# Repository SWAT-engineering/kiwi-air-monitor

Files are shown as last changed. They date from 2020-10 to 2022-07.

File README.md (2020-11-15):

<p align="center">
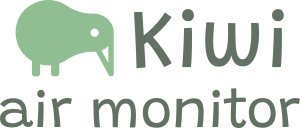
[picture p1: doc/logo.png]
Kiwi Monitor logo
    
</p>

Kiwi air monitor is an open source CO2/Humidity/Temperature sensor intended for monitoring the indoor air quality. Kiwi air monitor was initiated by [swat.engineering](https://www.swat.engineering) to support teachers and school organizations with the ventilation of the class rooms. 

## Features

- Monitor CO2, Humidity, Temperature, Atmospheric Pressure 
- Display current measurements and its trend on a small display
- Blink a warning light if certain thresholds are reached (> 800ppm CO2 for example)
- Optionally: publish sensor readings to a (self hosted) MQTT server to allow building wide monitoring
- Optionally: partial remote control via MQTT
- Optionally: Updating firmware over wifi (OTA) 
- Optionally: Docker-compose based Dashboard & MQTT server setup

<p align="center">
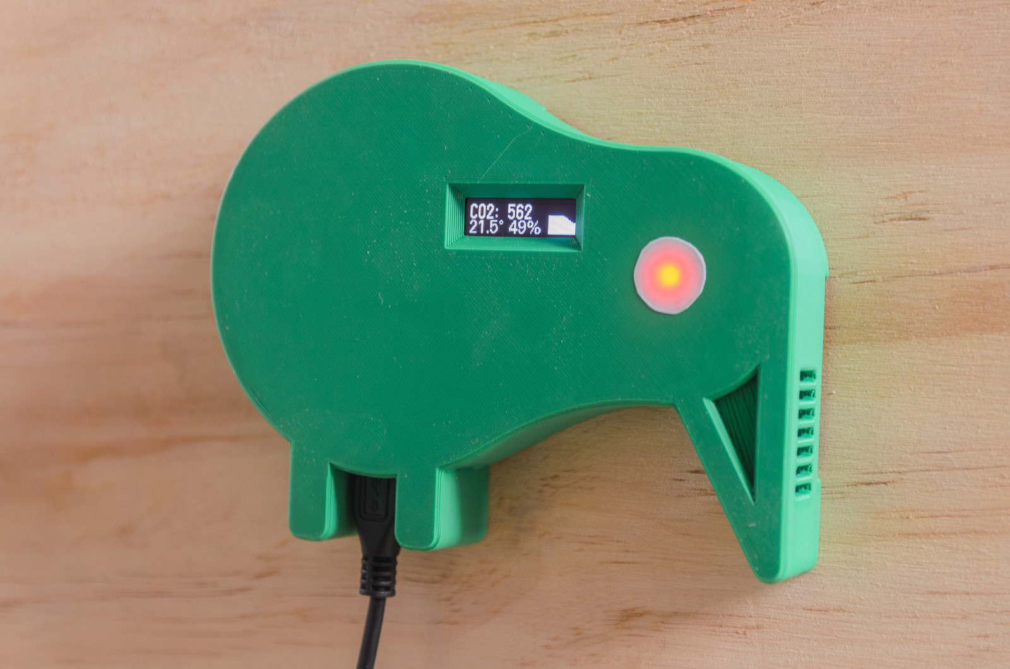
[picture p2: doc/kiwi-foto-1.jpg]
    
</p>

Due to the cost-cutting concern, we have focussed more on precision instead of accuracy. Meaning that if a value increases, it should indeed represent an increase in that property, but it is acceptable to have a bias with respect to more expensive measurements. So you might get a temperature of 20.4 degrees C even though it iss actually 20.9 degrees C but if it increases to 20.5 degrees C it indeed is now 21.0 degrees C.

## Hardware

The hardware is build around the ESP8266 platform. The costs (in the Netherlands) are roughly €45-50 per device. The list of components and schemas can be found in [doc/NL/Hardware.md](doc/NL/Hardware.md). We also provide a 3D model to print.

## Documentation
Please check out the documentation for further details and instructions about hardware and software, and user manuals:

1. [Dutch](doc/NL/)
2. [English](doc/ENG/) 

## Server

We've developed a small server setup (docker-compose based) so you can get started yourself. Checkout the [server/](server/) directory and the corresponding [documentation](docs/NL/Software.md).

## License

The software and 3D models are all [GPLv3 licensed](LICENSE). We use libraries with  compatible licenses. See [Software documentation](doc/NL/Software.md) for a list of which libraries are used.

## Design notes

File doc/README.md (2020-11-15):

This folder contains most documentation of the Kiwi Air Monitor.

The [Dutch Manual](NL/) is currently the most complete. 
Once it is finished we'll start translating it to [English](ENG/).

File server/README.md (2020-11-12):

# Server documentation & setup for Kiwi

The Kiwi Air Monitor can optionally send measurements to an MQTT server. This allows for building management and remote updates of settings & firmware.

This directory contains:

- `demo-config`: a docker-compose configuration for mqtt, influx, our own forwarder from mqtt to influx, and grafana for dashboards
- `mqtt-2-influx`: a small forwarder that takes kiwi sensor messages, optionally adds extra tags (such as building specific meta data) and inserts it into the `kiwi` database on influx
- `generator`: a small program that can fake one or more kiwi sensors. This is useful for testing and developing the server side.
- `doc`: documentation about the mqtt messages, and several setup related documentation and advice

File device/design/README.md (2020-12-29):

# The Kiwi Monitor hardware

These are the design files for the version1.0 PCB of the Kiwi Air Monitor. The project has been designed using KiCad EDA.

All components can be "plugged" into the board on the female header connectors.

See the [../../doc/](../../doc/) folder for design documentation.

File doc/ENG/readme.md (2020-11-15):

This folder will contain the english instructions. Sorry, we are currently working on the Dutch documentation, but we would love contributions for translations, but be warned, the Dutch translation is still in flux at the moment.

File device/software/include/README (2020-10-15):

Configuration file for you version of the Kiwi sensor.

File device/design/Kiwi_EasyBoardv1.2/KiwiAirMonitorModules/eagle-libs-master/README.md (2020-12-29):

Eagle Libraries
===============

Footprints of some electronic parts for Eagle v6.0 or greater:

 * **mh-z19.lbr** - [MH-Z19 NDIR CO2 sensor module](http://eleparts.co.kr/data/design/product_file/SENSOR/gas/MH-Z19_CO2%20Manual%20V2.pdf)

License Information
-------------------

This library collection is released under the [Creative Commons ShareAlike 4.0 International](https://creativecommons.org/licenses/by-sa/4.0/) license. Feel free to use these libraries for any purposes.

Improvements and fixes are welcome. Just fork repository, modify it and create pull request with changes.

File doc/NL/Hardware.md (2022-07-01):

# Hardware

Om alle componenten op een makkelijke en zekere manier met elkaar te verbinden hebben we een PCB ontworpen zoals hieronder te zien. We zijn nog bezig een manier te vinden dit PCB voor anderen beschikbaar te maken.

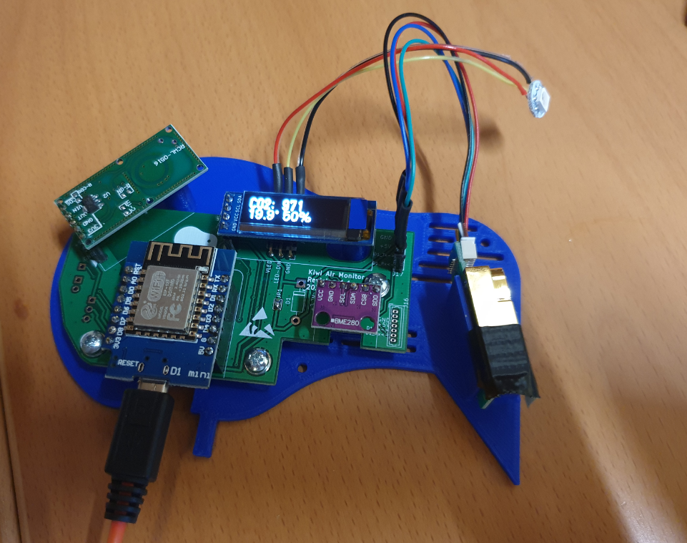
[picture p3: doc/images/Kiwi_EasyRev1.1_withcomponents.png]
KiwiEasyBoard Rev1.1


## Bestellijst 

De hardware is ontworpen rondom een ESP8266 platform. De kosten voor alle componenten zijn ongeveer 45-50 euro per apparaat. Hieronder links naar de verschillende componenten (hoeft niet perse daar gekocht te worden). 

- [Wemos D1 Mini - ESP8266-12F](https://www.tinytronics.nl/shop/en/communication/wi-fi/d1-mini-esp8266-12f-ch340) Zorg ervoor dat je de versie koopt met de "deksel" deze is FCC gekeurd en geeft minder storing op de bewegingssensor.
- [Winsen MH-Z19C CO2 Sensor](https://www.tinytronics.nl/shop/nl/sensoren/temperatuur-lucht-vochtigheid/winsen-mh-z19c-co2-sensor-met-kabel): We gebruiken nu de **versie C**. Deze is stabieler dan de versie B en volgens de specificaties ook nauwkeuriger. Deze versie word op het PCB aangesloten met het bijgeleverde kabeltje via een 7-pins PicoBlade connector. Vanwege hoge temperaturen word solderen direct op de sensor afgeraden. De MH-Z19 is een NDIR-type CO2 sensor, die na calibratie een goede sensitiviteit heeft. De nauwkeurigheid is echter niet vergelijkbaaar met een industriele sensor (4 a 5 keer zo duur). De echte CO2 waarde kan ongeveer 50 ppm hoger of lager zijn, maar de trend en de grove waardes zijn voor dit doeleinde meer dan genoeg.
- [BME280 I2C Temperature/Humidity Sensor](https://www.tinytronics.nl/shop/nl/sensoren/temperatuur-lucht-vochtigheid/bme280-digitale-barometer-druk-en-vochtigheid-sensor-module): zorg ervoor dat je een versie aanschaft die geconfigureerd is voor I2C, of zorg ervoor dat je het om kunt zetten van SPI naar I2C. BMP280 is ook prima. [Tests](http://www.kandrsmith.org/RJS/Misc/Hygrometers/calib_many.html) hebben laten zien dat de metingen accuraat en stabiel zijn. Afhankelijk hoe de sensor geconfigureerd wordt, zal de temperatuur een beetje onder of boven de echte waar zijn. Soldeer de header connector zo, dat de sensor aan de onderkant zit.
- [RCWL-0516 movement sensor](https://www.tinytronics.nl/shop/en/communication/rf/microwave-movement-sensor-rcwl-0516) een kleine sensor die beweging tot 7 m kan detecteren. In dit project wordt deze vooral gebruikt om te detecteren of er mensen aanwezig zijn en of het dus nodig is om iets op het display van de kiwi air monitor te laten zien (of dat het scherm uit kan). Soldeer de header connector zo, dat de componenten aan de onderkant zitten en de labels aan de bovenkant. 
- [SSD1306 128x32 OLED screen I2C](https://www.tinytronics.nl/shop/nl/display/oled/0.91-inch-oled-display-128*32-pixels-wit-i2c): zorg ervoor dat het een I2C versie is en een SSD1306 chipset heeft. Merk maakt niet veel uit. 
- [WS2812B RGB Led](https://www.tinytronics.nl/shop/nl/verlichting/led-digitaal/ws2812b-digitale-5050-rgb-led-printplaat-los-wit): Per apparaat is maar een ledje nodig, maar je kunt ook een hele strip kopen en er andere leuke dingen mee doen. De LED gestuurd word vanuit de D1Mini met spanning tussen 0V-3.3V. Volgens de WS2812B specificatie ligt het logisch '1' schakelniveau van deze chip op 0.7*VDD. Bij een Voedingsspanning van 5.0V zou de chip dus 3.5V op zijn data-in moeten hebben. Om dit probleem te omzeilen hebben we een diode in het voedingspad naar de LED gezet zodat we een spanning krijgen van 5.0V-0.7V=4.3V. Het logisch '1' schakel niveau komt hierdoor te liggen op 0.7 * 4.3 = 3.01V. Parallel aan de diode zit een soldeer brug.
- [7 pins Molex PicoBlade connector](https://sinuss.nl/zoeken?keyword=53047-0710): Connector om de MH-Z19C met het PCB te verbinden
- Kiwi Easyboard PCB: We hebben een PCB ontworpen waardoor de componenten makkelijk met elkaar verbonden kunnen worden.  De design files in KiCad en de gerbers zijn [hier beschikbaar](../../device/design/). De huidige versie is v1.1

Onderdelen die ook nodig zijn, maar waarvan we aannemen dat je die al hebt:
- USB oplader (500ma zou genoeg moeten zijn) of alternatief een powerbank, per dag ongeveer 800mAh rekenen.
- Micro-USB kabel
- Kabeltjes om de LED met de PCB te verbinden
- Een stel headers: Female voor op het PCB. Male voor aan de sensorren. (Sommige sensoren worden geleverd met pin headers).
- Soldeerbout
- Voor exprimenteren: Breadboard en kabeltjes om te experimenteren
  
## Stroomverbruik

De Kiwi verbruikt per uur ongeveer 30mAh. Meeste simple USB voedingen voldoen (500mA is ruim voldoende). Daarnaast zijn we een uitbreiding aan het ontwikkelen voor powerbanks erbij op te hangen. Op een powerbank van 2500mAh kun je makkelijk 3 dagen mee draaien. En powerbanks van 6000mAh of meer kun je een week mee vooruit.

## Montage instructies

### Schema

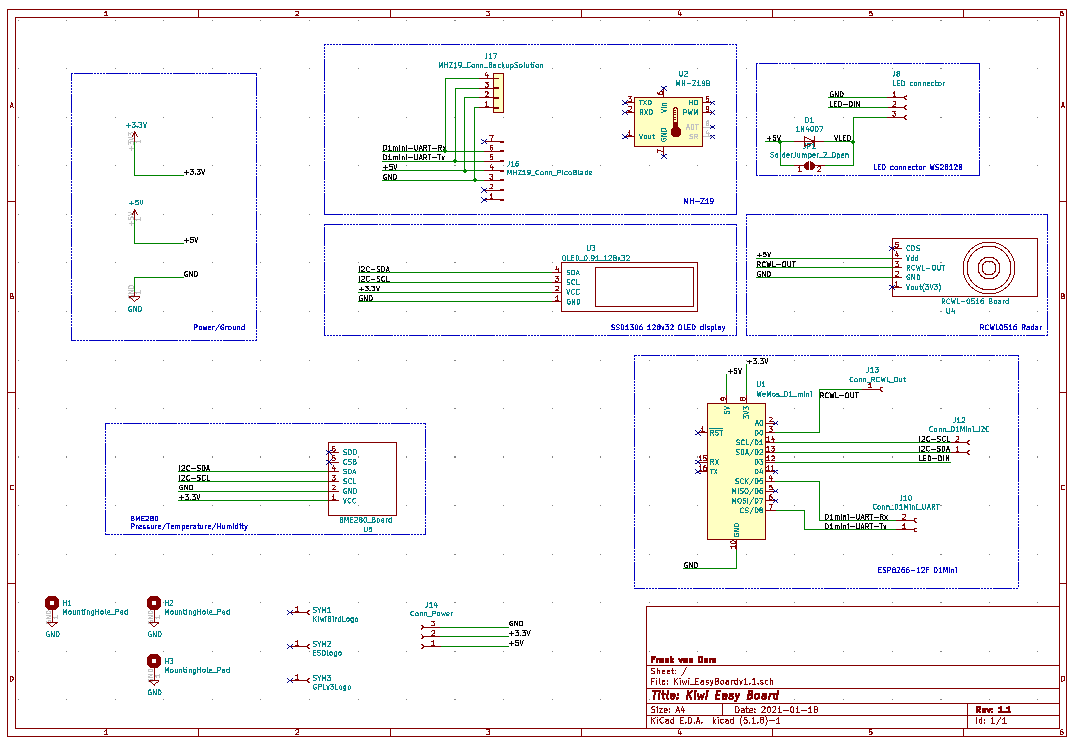
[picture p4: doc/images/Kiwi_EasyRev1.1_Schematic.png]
Wire schema
 

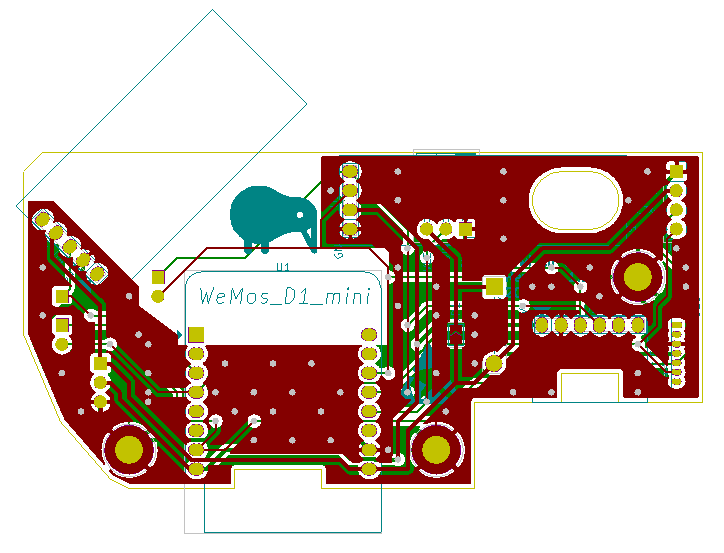
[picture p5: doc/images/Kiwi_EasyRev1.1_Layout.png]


Hieronder een samenvatting van de verbindingen:

| Component | Component side | Wemos D1 Mini |
| --- | --- | --- |
| MH-Z19C | VCC | 5V |
| | GND | G (GND) |
| | TX (Groene ader) | UART-Rx (D5) |
| | RX (Blauw ader) | UART-Tx (D8) |
| BME280 & SSD1306 | VCC | 3.3V |
| | GND | G |
| | SCL/SCK | D1 |
| | SDA | D2 |
|WS2812B | VDD | 5V |
| | VSS | G |
| | DIN | D3 |
| RCWL-0516 | VCC/VIN | 5V |
| | VOUT | D0 |
| | GND | G |

Hieronder ook het schema voor experimenten met breadboard view.

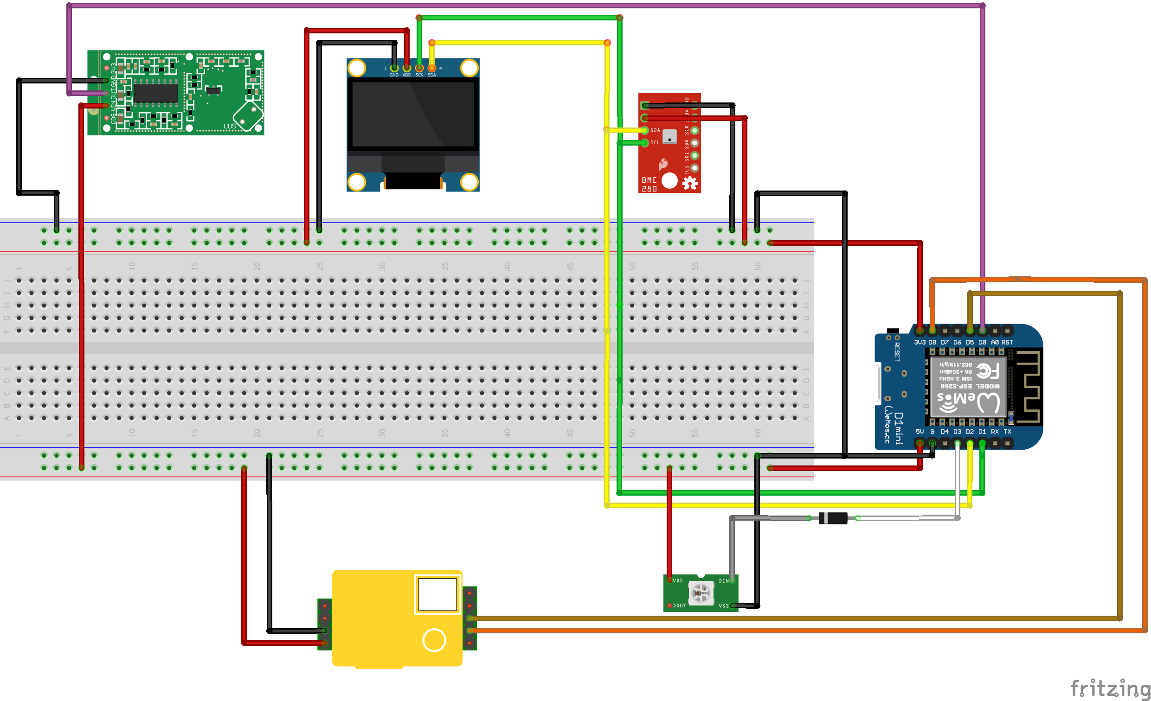
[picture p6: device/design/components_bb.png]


## Soldeer instructies

het is belangrijk de header connectors loodrecht op de PCB te solderen. Indien dit niet goed gebeurd zullen de componenten scheef komen te zitten en past het geheel misschien niet in de behuizing. Om het solderen makkelijker te maken hebben we een mal ontworpen die eenvoudig op een 3D printer is te maken.  De 3D printfile is [hier te <a href="../../device/design/Kiwi_EasyBoardv1.1/Kiwi1.1.SolderHelper.stl"> hier te vinden</a> (right-click to download)

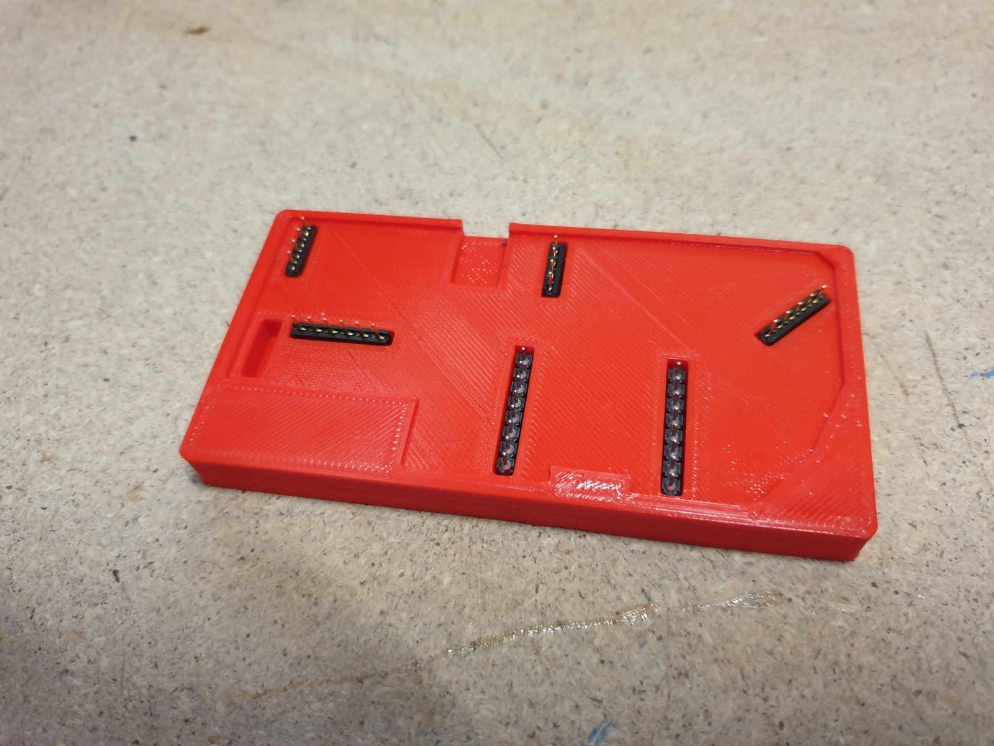
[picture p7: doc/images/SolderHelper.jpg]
Kiwi Solderhelper with PCB


Knip de header connectors eerst precies op maat en leg ze daarna in de soldeermal. Leg het PCB erboven op.

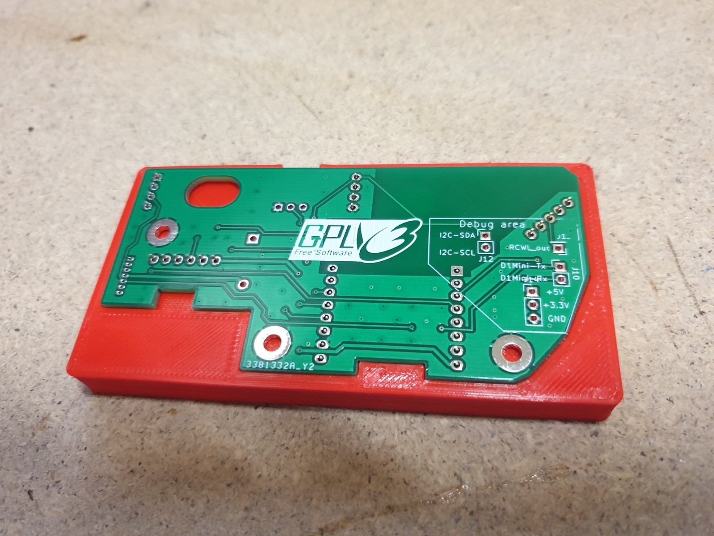
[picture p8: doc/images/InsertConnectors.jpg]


Soldeer alle pinnen netjes en check of het tin goed gevloeid heeft

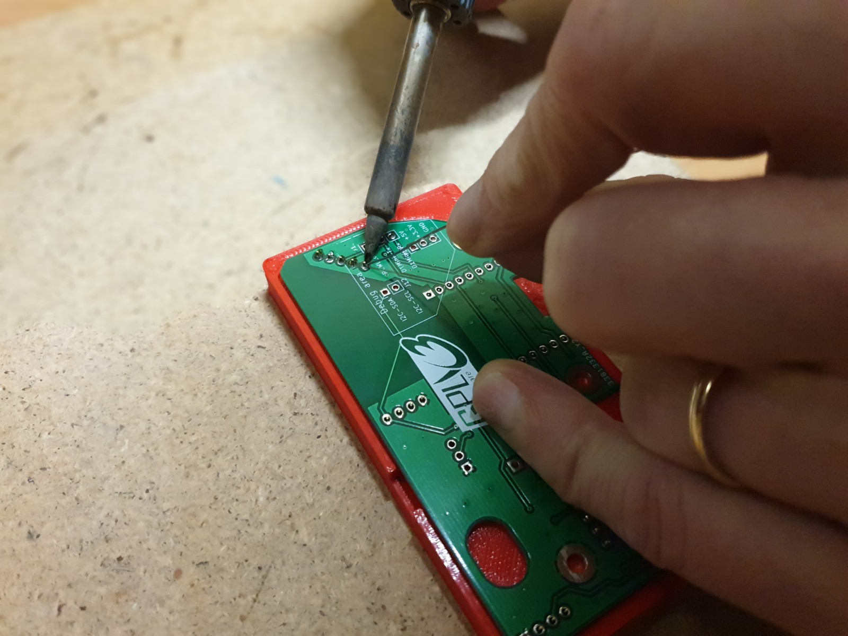
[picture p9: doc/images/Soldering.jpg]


Je PCB is nu klaar en je kunt de componenten er nu voorzichtig in drukken

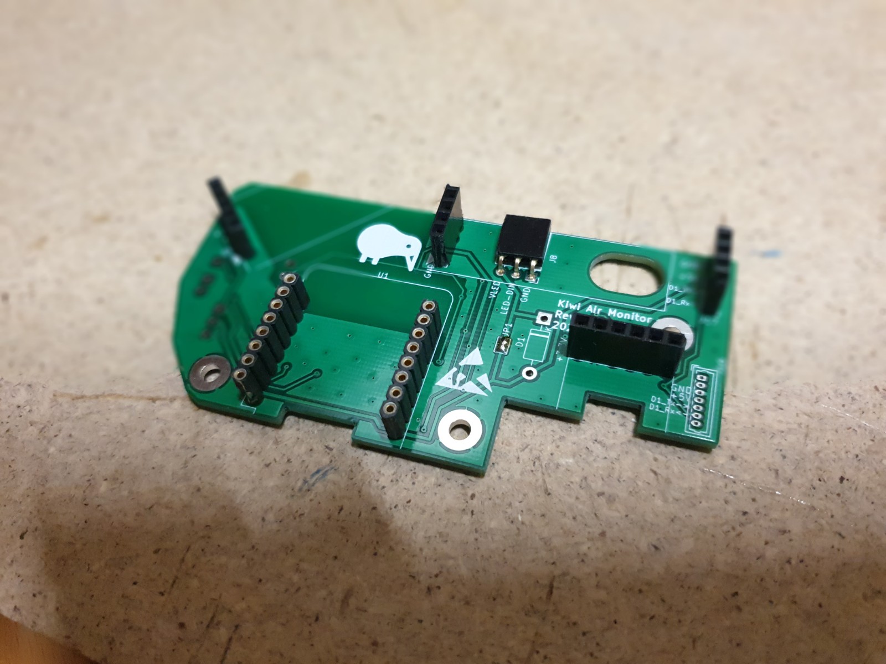
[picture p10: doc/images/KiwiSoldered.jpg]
Kiwi Solderhelper with PCB


**MH-Z19C kabel**: Op de KiwiEasyBoard 1.1 zitten 2 opties om de MH-Z19 CO2 sensor te verbinden. Het makkelijkste is het om de sensor via de meegeleverde kabel aan de 7-pins PicoBlade connector te verbinden. Indien je deze connector niet kunt verkrijgen kun je een kabel maken zoals op onderstaande foto. Op de PCB zit naast de PicoBlade ook een 4 pins header connector.

knip de connector die bij de CO2 sensor zit af aan één kant. Knip de bruine, witte en gele aders weg. Er blijven 4 over: zwart, rood, blauw, en groen. Verbind deze 4 kabels in dezelfde volgorde aan 4 pinheaders.

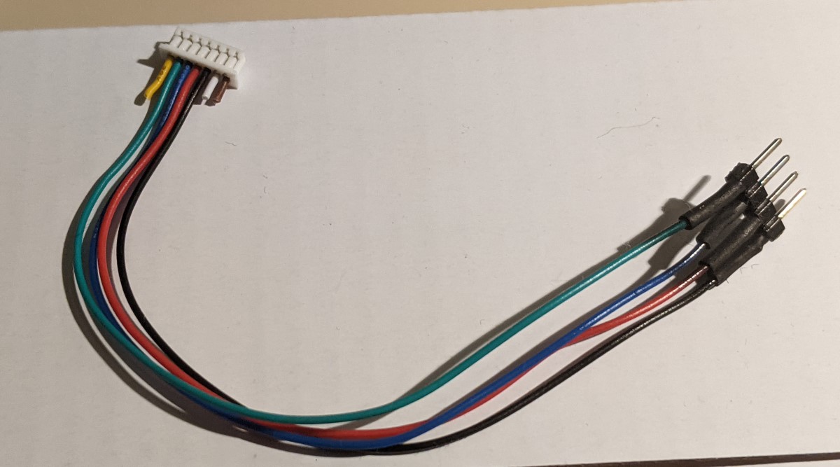
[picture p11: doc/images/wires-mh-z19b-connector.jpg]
MH-Z19B connector


## Behuizing

Om de elektronica te beschermen en netjes weg te werken, is het goed om er een behuizing om heen te maken. Er is een ontwerp gemaakt in de vorm van een kiwi vogel dat met een 3D-printer afgedrukt kan worden. In dit model passen precies alle componenten die hierboven beschreven zijn. Als je geen 3D printer tot je beschikking hebt of liever zelf iets anders maakt. Zie hieronder dan ook een aantal tips waar je aan moet denken bij het ontwerp.

### 3D-printen van behuizing

TODO: link naar 3D model + extra uitleg? eventueel een foto?

### Adviezen voor eigen ontwerp

- Zorg ervoor dat componenenten niet te dicht bij elkaar zitten
- De CO2 sensor wil graag frisse lucht, hoe er rekening mee dat er genoeg frisse lucht langs kan stromen. Zowel voor afkoeling als voor accurate meting.
- Temperatuur en lucht vochtigheids sensor willen ook frisse lucht, en hebben de voorkeur om niet te warm te worden van componenten om hen heen.
- de bewegings sensor kan storing krijgen van de ESP8266 chip, dus probeer ze niet te dicht bij elkaar te zetten.
- de bewegings sensor werkt door plastic heen, maar wil wel in 1 cm rond het object liever geen metaal. (dus ook draadjes liever niet teveel)

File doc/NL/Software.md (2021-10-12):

# Sensor software
De software voor de Kiwi air monitor is ontwikkeld voor dit project en maakt gebruik van de volgende frameworks en libraries:

- [ESP8266 Arduino Core](https://github.com/esp8266/Arduino) 
- [olikraus' U8g2](https://github.com/olikraus/U8g2)
- [Adafruit MQTT](https://github.com/adafruit/Adafruit_MQTT_Library)
- [Adafruit BME280](https://github.com/adafruit/Adafruit_BME280_Library)
- [Adafruit NeoPixel](https://github.com/adafruit/Adafruit_NeoPixel)
- [Arduino Timer](https://github.com/contrem/arduino-timer)
- [WifWafs MH-Z19](https://github.com/WifWaf/MH-Z19)

## Configuratie instructies

Het project wordt gecompileerd met [Platform IO](https://platformio.org/). 

In de bestandsmap device\software\include staat het bestand user-config-template.h, in dit bestand kan persoonlijke informatie worden aangepast.
Dit betreft informatie zoals wifi en MQTT credentials. is hier geen noodzaak voor dan hoeft het bestand niet aangepast te worden.

Na het aanpassen van het bestand dient deze opgeslagen te worden als user-config.h, belangrijk is dat het nieuw opgeslagen bestand in de bestandsmap staat als de template.
TODO: beschrijf hier de configuratie instructies

## Uploaden van firmware
De ESP8266 kan geprogrameerd worden dmv de USB aansluiting en als WiFi & MQTT geconfigureerd zijn, kan erna ook online updates uitgevoerd worden (OTA). 

### Eerste keer uploaden

Na het compileren en configureren van de Kiwi software, moet de USB kabel aan de computer worden aangesloten, en de firmware ge-upload worden.

TODO: script schrijven die dit makkelijk maakt

### Updates uitvoeren via wifi (OTA)
Als de firmware eenmaal op het apparaat staat, kunnen updates gedaan worden via wifi. 

Hiervoor moeten de volgende zaken geconfigureerd worden:

- MQTT & WIFI setup voor de Kiwi
- Signing key for the updates geconfigureeerd voor de Kiwi
- Http server waar de firmware op zal bevinden

TODO: script voor compilate & signing schrijven

## Monitoring dashboard (optioneel)
Het is mogelijk om de metingen door te sturen naar een monitoring dashboard (grafana & influxdb).
Dit biedt het de mogelijkheid om tijdstrends van de gemeten waardes per ruimte in kaart te brengen.
Hieronder volgen instructies hoe je zo'n dashboard aan kunt maken en inrichten. 
De code voor een voorbeeld-dashboard is beschikbaar in de [server directory](../../server/) van deze github repository.

### Architectuur
De verbinding met de Kiwi loopt via MQTT, dit berichten protocol ontkoppeld de Kiwi van iedereen die er interesse in heeft.
Daarnaast kan er ook gecommuniceerd worden richting de Kiwi's via MQTT.
Hierdoor wordt het mogelijk om van een afstand updates te installeren of settings aan te passen.

Een simpele forwarder stuurd MQTT berichten door naar een influx database. Deze forwarder kan ook extra annotaties aan metingen hangen, zoals de naam van een klaslokaal of een gebouw code.
Vervolgens kun je zelf een dashboard maken met [granfana](https://grafana.com/). Een initiële configuratie wordt al geboden in onze voorbeeld server setup.

In [server/mqtt.md](../../server/mqtt.md) staat beschreven welke berichten er gepubliceerd worden op de MQTT server en welke gestuurd kunnen worden richting de Kiwi.

### Voorbeeld server installatie

Als voorbeeld setup hebben wij een kleine server installatie klaargezet. Middels docker-compose kan deze op elke Linux, Windows, of OSX omgeving gedraaid worden. Het moet zelfs mogelijk zijn om een recente raspberry-pi 4 als server te gebruiken hiervoor.

De server directory bevat:
- `demo-config`: een docker configuratie voor mqtt, influx, een forwarder van mqtt naar influx, en grafana voor het visualiseren van het dashboard. 
- `mqtt-2-influx`: een forwarder die de metingen van de Kiwi air monitor (eventueel met extra tags) doorstuurt naar de `kiwi` database voor influx.
- `generator`: een klein programmaatje dat een kiwi sensor simuleert. Dit is nuttig voor het ontwikkelen en testen van de server kant.
- `doc`: een paar extra details over de mqtt berichten die niet passen in deze meer high-level handleiding.

De configuratie van de mqtt-2-influx forwarder wordt uitgelegd in de handleiding in die directory.

## Wil je bijdragen aan software ontwikkelingen?
Heb je ideeën om de software uit te breiden of aan te passen? Bijdrages zijn welkom, neem even contact met ons op van te voren om af te stemmen.

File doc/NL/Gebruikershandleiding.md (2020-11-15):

# Gebruikershandleiding

TODO: deze handleiding invullen en uitbreiden

## Wat betekenen de getallen die op de display te zien zijn?

## Kleur van het ledje

## Hoe moet ik de resultaten interpreteren?

## Wat moet ik doen als de CO2 grenswaarde wordt overschreden?

## Wat kan ik leren van de gegevens op het dashboard?

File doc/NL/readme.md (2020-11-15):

De Kiwi air monitor is een open source project waarin een sensor ontwikkeld is om de lucht kwaliteit te meten in een ruimte aan de hand van de CO2, luchtvohtigheid en temperatuur. Dit project is opgestart door [swat.engineering](https://www.swat.engineering) om docenten en schoolorganisaties te helpen bij het ventileren van de klaslokalen.

In deze folder is alle Nederlandstalige documentatie te vinden rondom het monteren en configureren van de Kiwi air monitor. 

In '[Hardware](Hardware.md)' vind je een beschrijving van de benodigde componenten, instructies voor montage en instructies met betrekking tot de behuizing.

In '[Software](Software.md)' vind je instructies rondom de software: configuratie settings, uploaden van de firmware en het monitor dashboard (optioneel)

In '[In gebruik nemen](In%20gebruik%20nemen.md)' vind je meer informatie over de stappen die genomen moeten worden nadat de hardware gemonteerd is en de software erop is gezet: calibratie van de CO2 sensor, tips voor het ophangen van de Kiwi air monitor en instructies voor het uitvoeren van software updates.

De '[Gebruikershandleiding](Gebruikershandleiding.md)' geeft nuttige tips en informatie voor de eindgebruiker van de Kiwi air monitor. 

Het document '[Educatief](Educatief.md]' is gereserveerd voor educatieve ontwikkelingen. Lijkt het je leuk om dit project om te zetten naar een lespakket voor de laatste klassen van de basisschool of voor lessen op de middelbare school, laat het ons weten en zoek contact op! 

Mochten er vragen zijn, open een [github issue](https://github.com/SWAT-engineering/kiwi-air-monitor/issues) of neem contact op met [davy.landman@swat.engineering](mailto:davy.landman@swat.engineering).

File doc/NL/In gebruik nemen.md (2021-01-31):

# In gebruik nemen

Als je de hardware en software geinstalleerd en geconfigureerd hebt, komt de volgende stap: het klaar maken voor gebruik. In dit document staat uitgelegd waar je rekening mee moet houden bij het ophangen van de kiwi en hoe je software updates kunt uitvoeren. De handleiding voor de eindgebruikers is in een appart document te vinden.

## Ophangen
Bij het ophangen van de sensor moet een geschikte plek gezocht worden in de ruimte. Houd hierbij rekening met het volgende:

TODO: lijstje met criteria voor het ophangen van de kiwi

## Onderhoud (updates)

- Updates voor de software kunnen automatisch lopen, mits dit is geconfigureerd via wifi & mqtt.
- Het ontwerp van de Kiwi is modulair, als een component beschadigd raakt, kan het makkelijk vervangen worden mits er van onze voorgestelde kabel boom gebruik is gemaakt.

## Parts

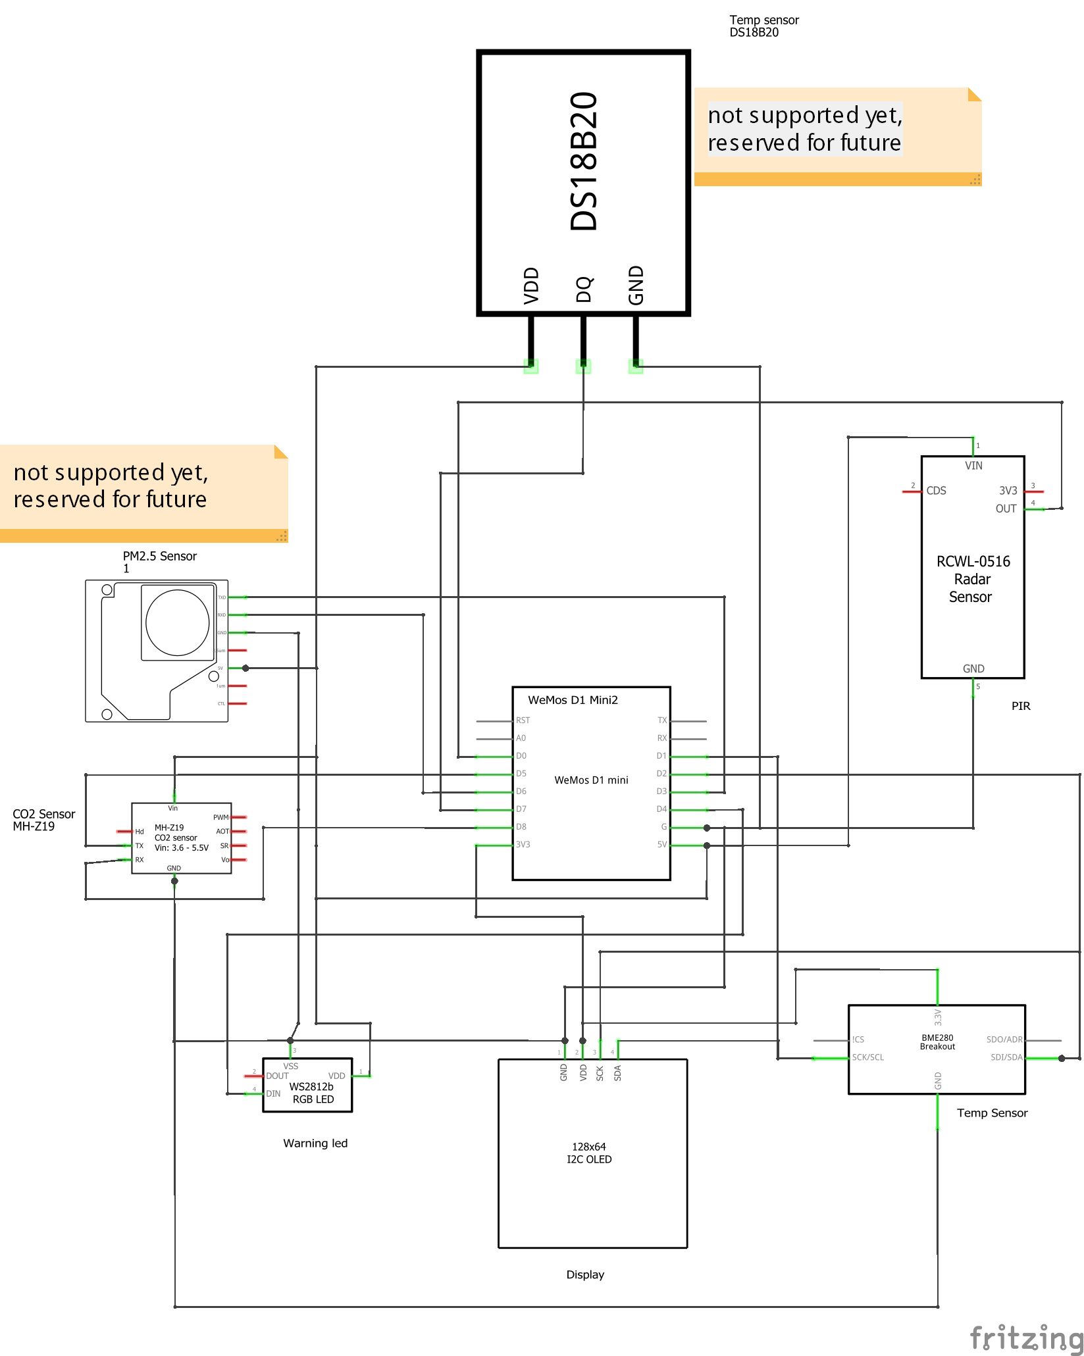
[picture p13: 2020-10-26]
device/design/components_schem.png

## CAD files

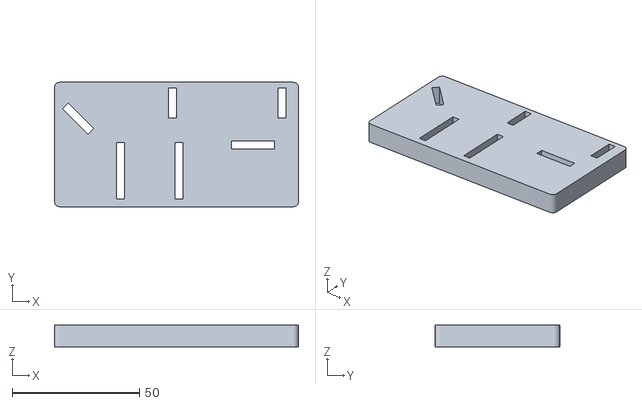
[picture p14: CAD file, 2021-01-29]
device/design/Kiwi_EasyBoardv1.1/Kiwi1.1.SolderHelper.stl
96.0 x 49.0 x 8.50

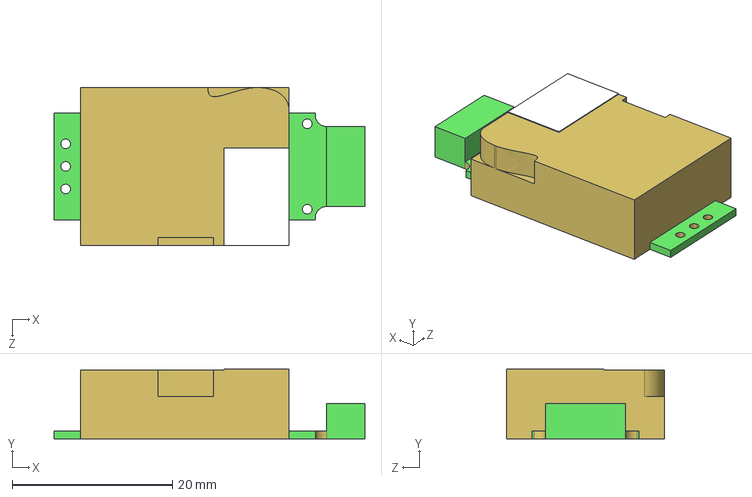
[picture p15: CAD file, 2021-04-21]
device/design/Kiwi_EasyBoardv1.2/KiwiAirMonitorModules/STEPfiles/MH-Z19C (CO2).STEP
38.8 x 8.70 x 19.7 mm

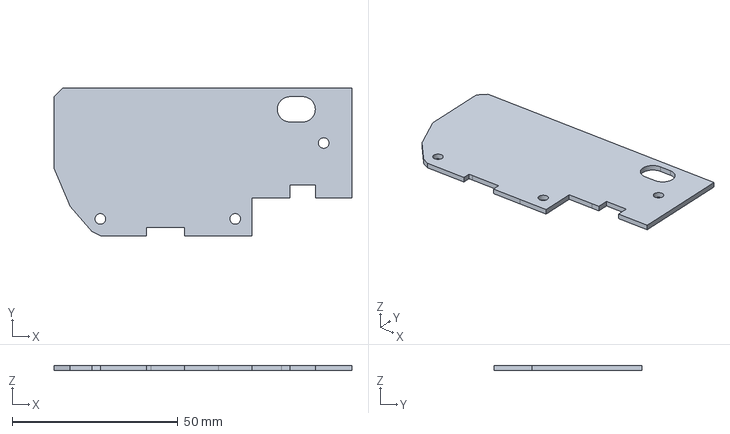
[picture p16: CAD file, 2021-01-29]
device/design/Kiwi_EasyBoardv1.1/Kiwi_EasyBoardv1.1.NoComponents.step
89.8 x 44.5 x 1.60 mm

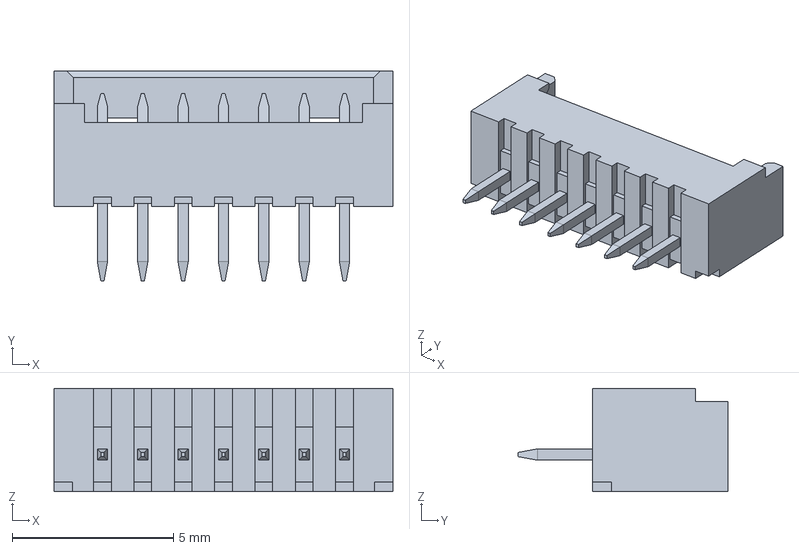
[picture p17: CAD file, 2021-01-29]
device/design/Kiwi_EasyBoardv1.2/KiwiAirMonitorModules/STEPfiles/Molex_PicoBlade_530470710.stp
10.5 x 6.50 x 3.20 mm

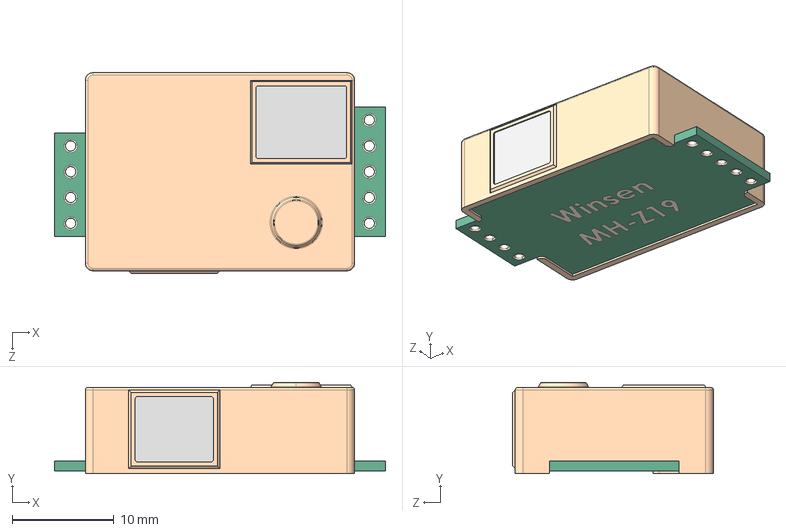
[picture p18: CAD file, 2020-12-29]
device/design/Kiwi_EasyBoardv1.2/KiwiAirMonitorModules/STEPfiles/User Library-Winsen - MH-Z19.STEP
32.6 x 9.00 x 19.7 mm

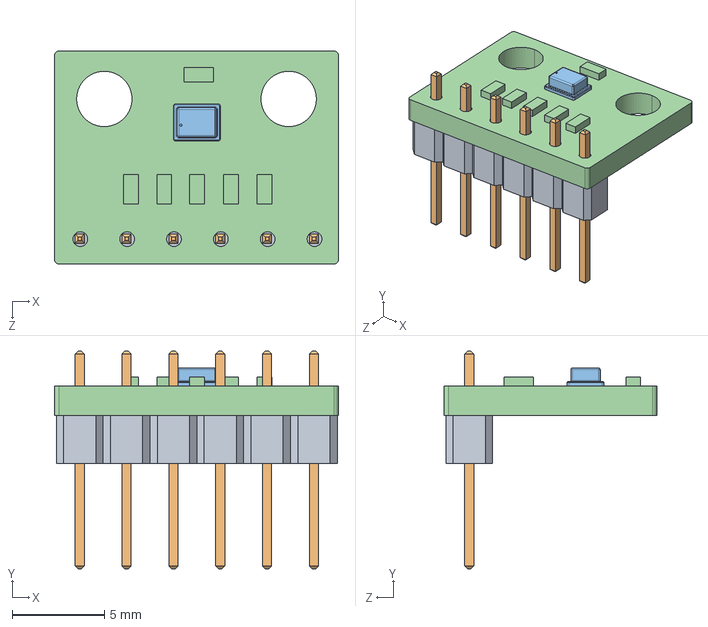
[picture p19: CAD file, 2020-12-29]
device/design/Kiwi_EasyBoardv1.2/KiwiAirMonitorModules/STEPfiles/BME280_SENSOR_MODULE_WITH_HEADER.STEP
15.4 x 11.8 x 11.6 mm

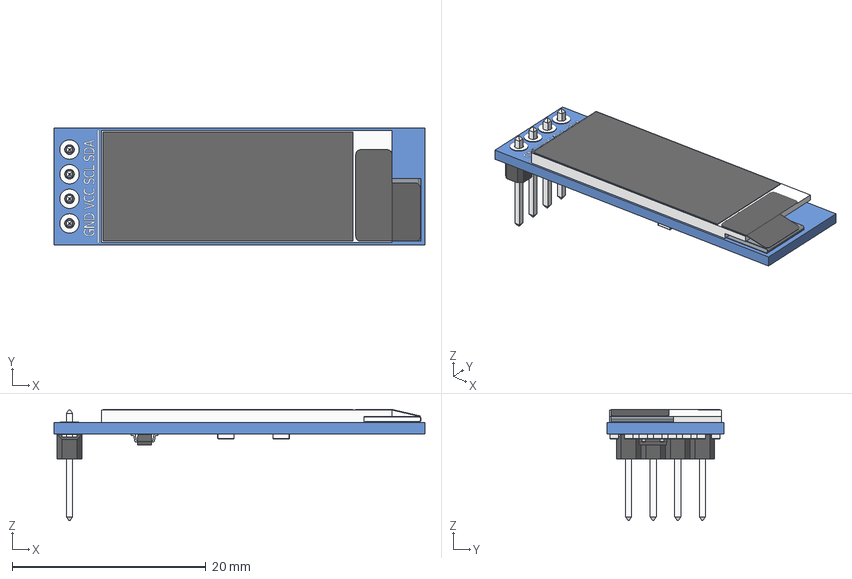
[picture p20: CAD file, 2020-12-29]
device/design/Kiwi_EasyBoardv1.2/KiwiAirMonitorModules/STEPfiles/OLED_0.91_128x32.stp
38.3 x 12.1 x 11.5 mm
OLED_0.91_128x32
Pin Header 4 x 1 TH 2.54mm Pitch
RESC-0603 x 13
2SD0601A

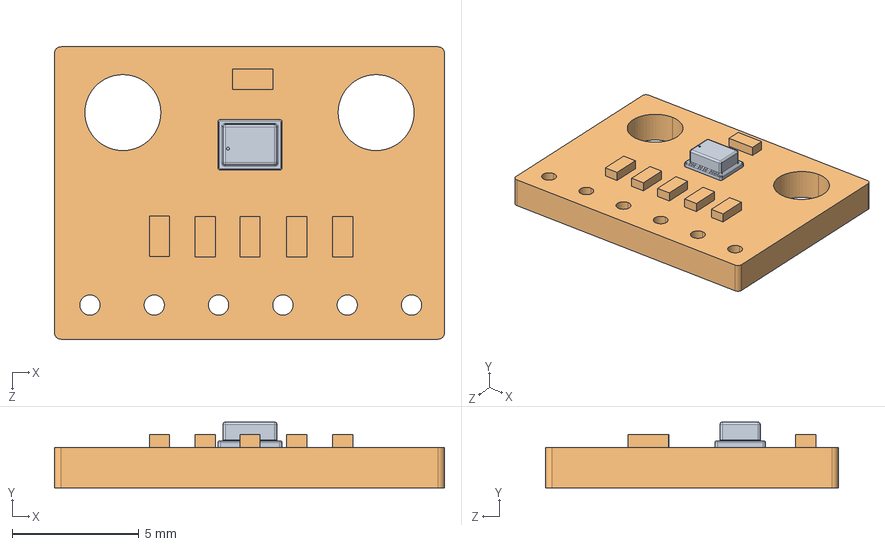
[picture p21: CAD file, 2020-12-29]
device/design/Kiwi_EasyBoardv1.2/KiwiAirMonitorModules/STEPfiles/BME280_SENSOR_MODULE.STEP
15.4 x 2.60 x 11.6 mm

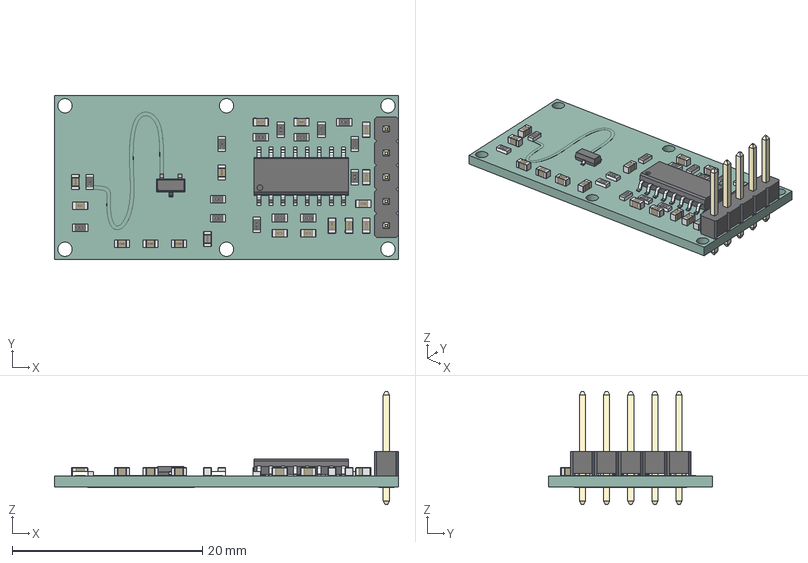
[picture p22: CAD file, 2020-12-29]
device/design/Kiwi_EasyBoardv1.2/KiwiAirMonitorModules/STEPfiles/RCWL-0516.step
36.2 x 17.3 x 11.9 mm
r-smd-0603 x 15
c-smd-0603 x 17
SO16
PinHeader
SOT23SMD v1

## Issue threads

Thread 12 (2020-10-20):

Write small program that only calibrates sensors

DavyLandman, 2020-10-20:
Detects sensors connected to some of the ports, then waits for 25 minutes, than sends the command to set the calibration point.

DavyLandman, 2020-12-02:
Finished

Closed 2020-12-02.

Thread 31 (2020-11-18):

Make mqtt connection more secure

DavyLandman, 2020-11-18:
The client already supports ssl and user/password protected connections, but the current docker-compose setup doesn't do this.

We should provide:

- a small script to generate a new certificate
- a way to generate user&password authentication
- pass this user&password along to the internal side of the mqtt-2-influxdb forwarder

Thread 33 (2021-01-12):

Re-design KIWI PCB revision 1.1

Frankvd81, 2021-01-12:
- [x] Instantiation of rev1.1 design database
- [x] bug fix: Rotate the OLED display connector 180degree
- [x] Modify the connector for the new MH-Z19-C with cable connector
- [x] Review placement of the BME280. The reported temperature is too high
- [x] Connector for the LED should move to a different location. Probably better use a 90degree connector for easier plug-in with short wires.
- [x] Check if we can move the pin controlling the LED to another Arduino pin. Currently it is assigned to D4, which is the same as the blue LED on the ESP8266 board. because of this we can not switch off the ESP8266 LED. Switch to either D3, D5 or D6
- [x] make the pads bigger for all components, comparable to the esp8266 pads
- [x] put the kiwi bird logo on the pcb (get the svg from [font awesome](https://fontawesome.com/icons/kiwi-bird) by clciking the download button)
- [x] add small labels on the pcb to help with allignment of the components (just like for the led). so maybe just write the pin for the GND connection on all of them?
- [x] annotate/decorate the debug pins so that a user knows to ignore them
- [x] flip the rcwl board, so that the other side is faceing front

Frankvd81, 2021-01-12:
I've started the redesign of the KIWI PCB. Add any issue found on the rev1.0 in this list so I can modify it for the next spin of the board

DavyLandman, 2021-01-12:
I've added a few points to the list.

- Moving the LED pin: I'll take a look. I think D3 is a good candidate
- bme280 is a though one, it's a sensitive one.. maybe space it so that it's less close to the co2 sensor?

Closed 2021-01-31.

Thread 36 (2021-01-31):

Switch to runtime configuration instead of compile time

DavyLandman, 2021-01-31:
As suggested by  @gertziel and @Frankvd81 it would be nice to configure the Kiwi after flashing the firmware.

Steps:

- [ ] put button on back of the kiwi to trigger "maintenance mode" that starts an access point and allows a user to upload a config file
- [ ] store config file in file system part of the memory
- [ ] replace most compile-time defines into runtime defines
- [ ] plot lacking wifi connectivity on screen
- [ ] release binaries using github actions

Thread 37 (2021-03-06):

Re-design KIWI PCB revision 1.2

Frankvd81, 2021-03-06:
- [ ] RCLW met chip zijde naar boven
- [ ] Knopje aan achterzijde van PCB aan een ESP GPIO
- [ ] !RST van de ESP verbinden met D0 (i.v.m sleep mode)
- [ ] RCWL-OUT naar een andere ESP GPIO
- [ ] CO2 plug switchable tussen 5V and 3V
- [ ] LED via [3 pin JST ](https://www.tinytronics.nl/shop/nl/kabels/jst/jst-xh-connector-met-kabel-en-printplaatconnector-3-pins)
- [ ] BME280 via [4 pins JST](https://www.tinytronics.nl/shop/nl/kabels/jst/jst-xh-connector-met-kabel-en-printplaatconnector-4-pins)
- [ ] Beslissen welke CO2 sensor we willen gebruiken en met welke connector (Picoblade, 4P-JST, allebei)

DavyLandman, 2021-03-06:
Co2 is toch beide 5v, dus dat hoeft niet. Flexibele naar 3v.

En ik zou zeggen, zowel picoblade pins als 4 jst. Dan kunnen we alle 3 de varianten aan. Want beide CO2 chips hebben 5v + uart.

Frankvd81, 2021-03-06:
ja. zag ik ook dus is niet nodig

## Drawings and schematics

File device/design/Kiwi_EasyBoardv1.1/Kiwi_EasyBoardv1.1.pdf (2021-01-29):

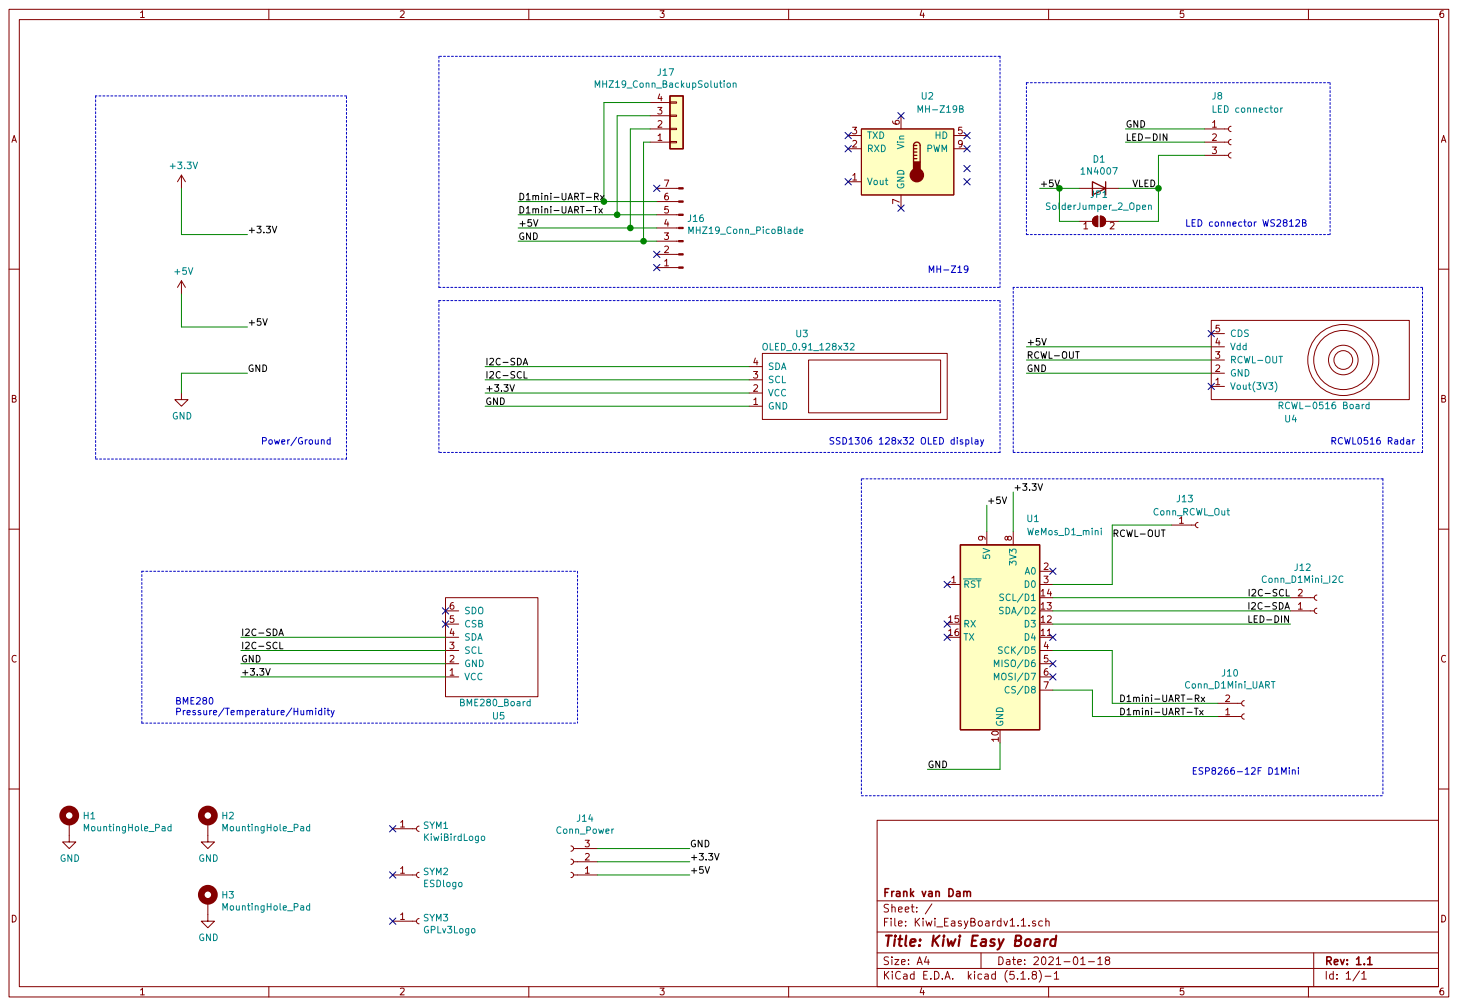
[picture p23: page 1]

D1mini-UART-Tx D1mini-UART-Rx

File: Kiwi_EasyBoardv1.1.sch Sheet: / Frank van Dam

Id: 1/1 Title: Kiwi Easy Board

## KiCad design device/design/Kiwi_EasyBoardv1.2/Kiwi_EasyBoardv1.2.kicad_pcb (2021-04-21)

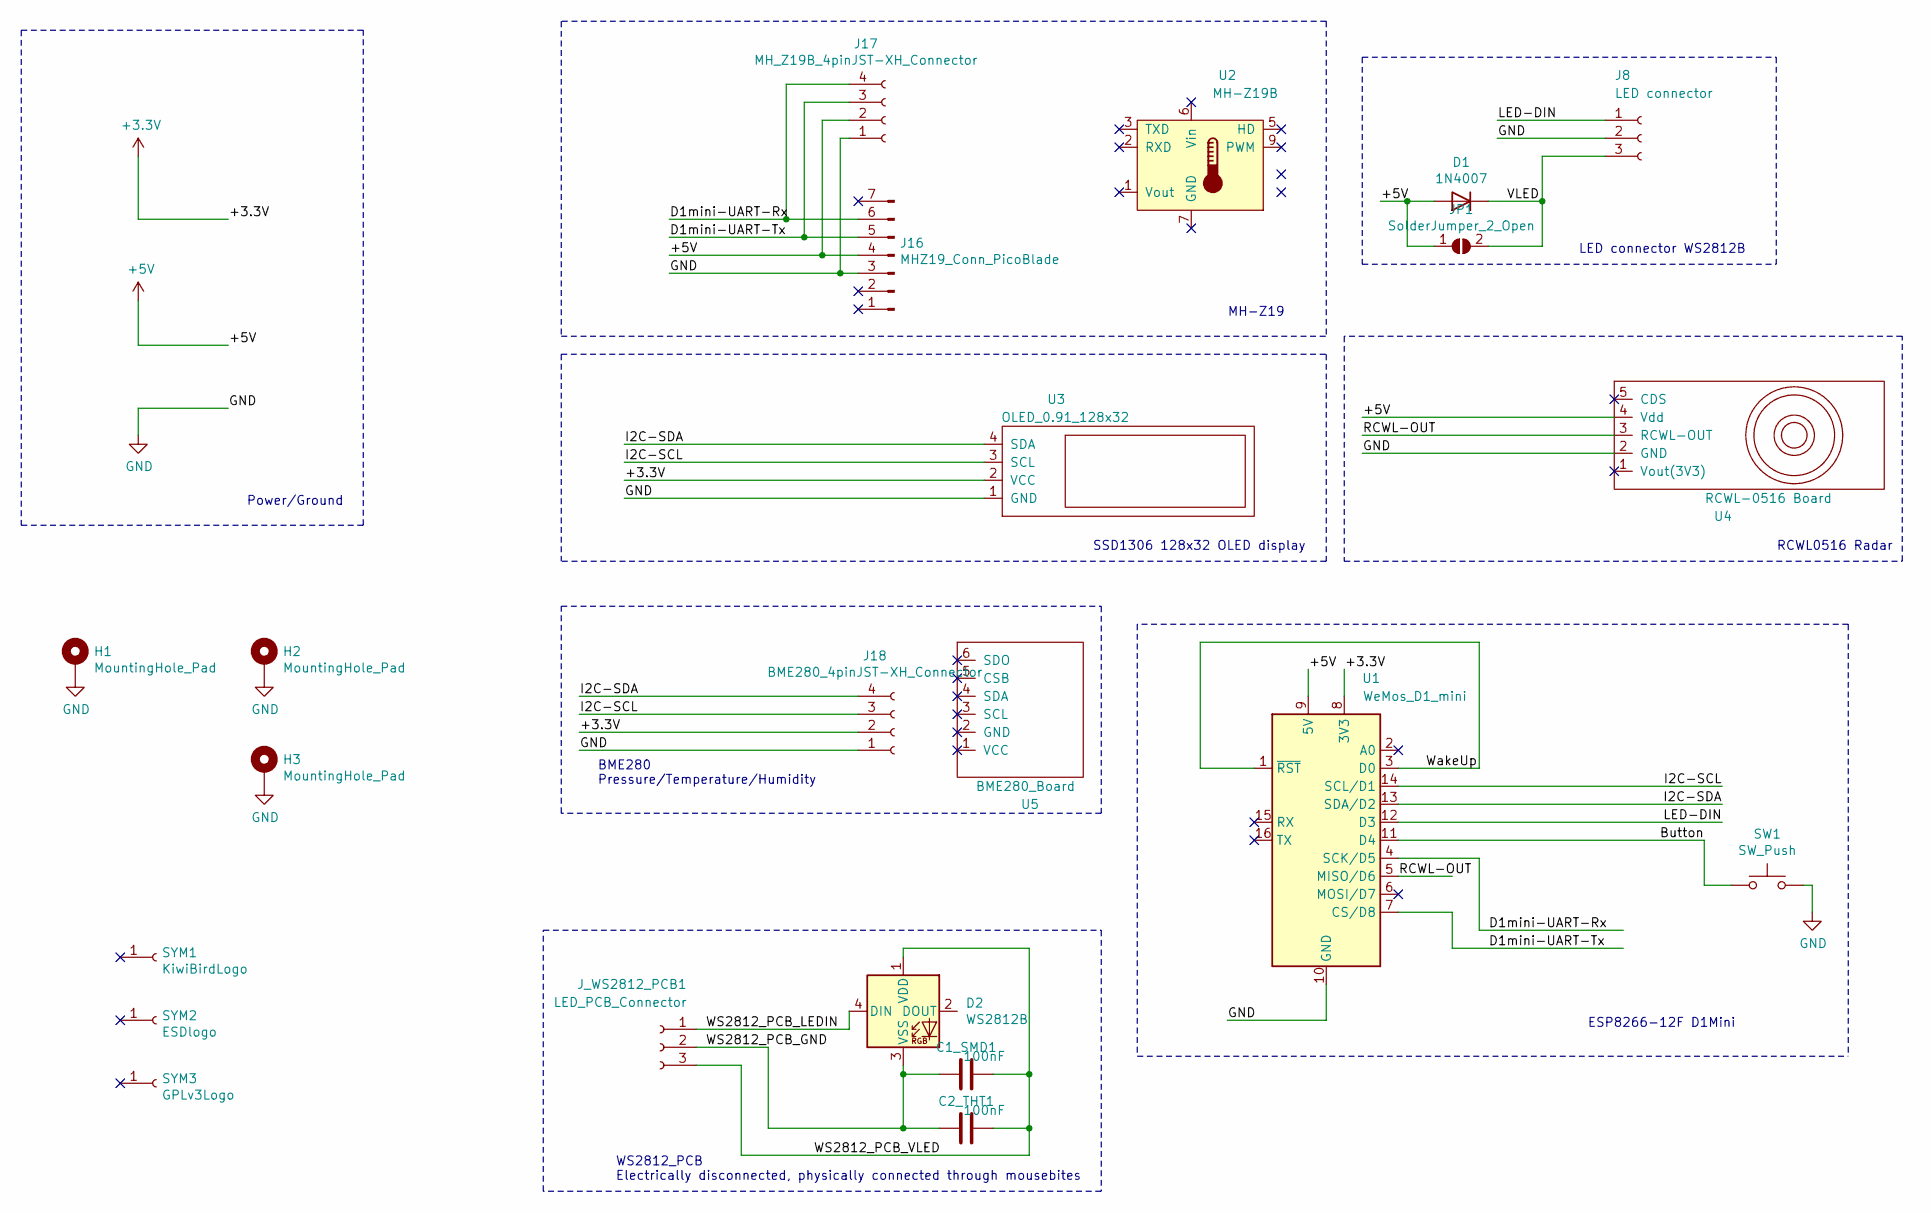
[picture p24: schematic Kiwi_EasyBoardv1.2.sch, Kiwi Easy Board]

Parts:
C1_SMD1: 100nF; C_0805_2012Metric_Pad1.18x1.45mm_HandSolder
C2_THT1: 100nF; C_Disc_D4.3mm_W1.9mm_P5.00mm
D1: 1N4007; D_DO-41_SOD81_P10.16mm_Horizontal
D2: WS2812B; LED_WS2812B_PLCC4_5.0x5.0mm_P3.2mm
H1, H2, H3: MountingHole_Pad; MountingHole_3.2mm_M3_Pad_TopBottom
J8: LED connector; JST_XH_B3B-XH-A_1x03_P2.50mm_Vertical
J16: MHZ19_Conn_PicoBlade; Molex_PicoBlade_53047-0710_1x07_P1.25mm_Vertical
J17: MH_Z19B_4pinJST-XH_Connector; JST_XH_B4B-XH-A_1x04_P2.50mm_Vertical
J18: BME280_4pinJST-XH_Connector; JST_XH_B4B-XH-A_1x04_P2.50mm_Vertical
JP1: SolderJumper_2_Open; SolderJumper-2_P1.3mm_Open_TrianglePad1.0x1.5mm
J_WS2812_PCB1: LED_PCB_Connector; PinHeader_1x03_P2.54mm_Vertical
SW1: SW_Push; SW_Tactile_Straight
SYM1: KiwiBirdLogo
SYM2: ESDlogo; ESD-Logo_8.9x8mm_SilkScreen
SYM3: GPLv3Logo; GPL3
U1: WeMos_D1_mini; WEMOS_D1_mini_light
U2: MH-Z19B; Winsen_MH-Z19B
U3: OLED_0.91_128x32
U4: RCWL-0516 Board; RCWL-0516
U5: BME280_Board

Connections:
+3V3: J18.2, U1.8 (3V3), U3.2 (VCC)
+5V: D1.2 (A), J16.4, J17.2, JP1.1 (A), U1.9 (5V), U4.4 (Vdd)
/Button: SW1.1, U1.11 (D4)
/D1mini-UART-Rx: J16.6, J17.4, U1.4 (SCK/D5)
/D1mini-UART-Tx: J16.5, J17.3, U1.7 (CS/D8)
/I2C-SCL: J18.3, U1.14 (SCL/D1), U3.3 (SCL)
/I2C-SDA: J18.4, U1.13 (SDA/D2), U3.4 (SDA)
/LED-DIN: J8.1, U1.12 (D3)
/RCWL-OUT: U1.5 (MISO/D6), U4.3 (RCWL-OUT)
/VLED: D1.1 (K), J8.3, JP1.2 (B)
/WS2812_PCB_GND: C1_SMD1.1, C2_THT1.1, D2.3 (VSS), J_WS2812_PCB1.2
/WS2812_PCB_LEDIN: D2.4 (DIN), J_WS2812_PCB1.1
/WS2812_PCB_VLED: C1_SMD1.2, C2_THT1.2, D2.1 (VDD), J_WS2812_PCB1.3
/WakeUp: U1.1 (~RST), U1.3 (D0)
GND: H1.1, H2.1, H3.1, J8.2, J16.3, J17.1, J18.1, SW1.2, U1.10 (GND), U3.1 (GND), U4.2 (GND)

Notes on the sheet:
MH-Z19
ESP8266-12F D1Mini
Power/Ground
SSD1306 128x32 OLED display
RCWL0516 Radar
LED connector WS2812B
BME280 Pressure/Temperature/Humidity
WS2812_PCB Electrically disconnected, physically connected through mousebites

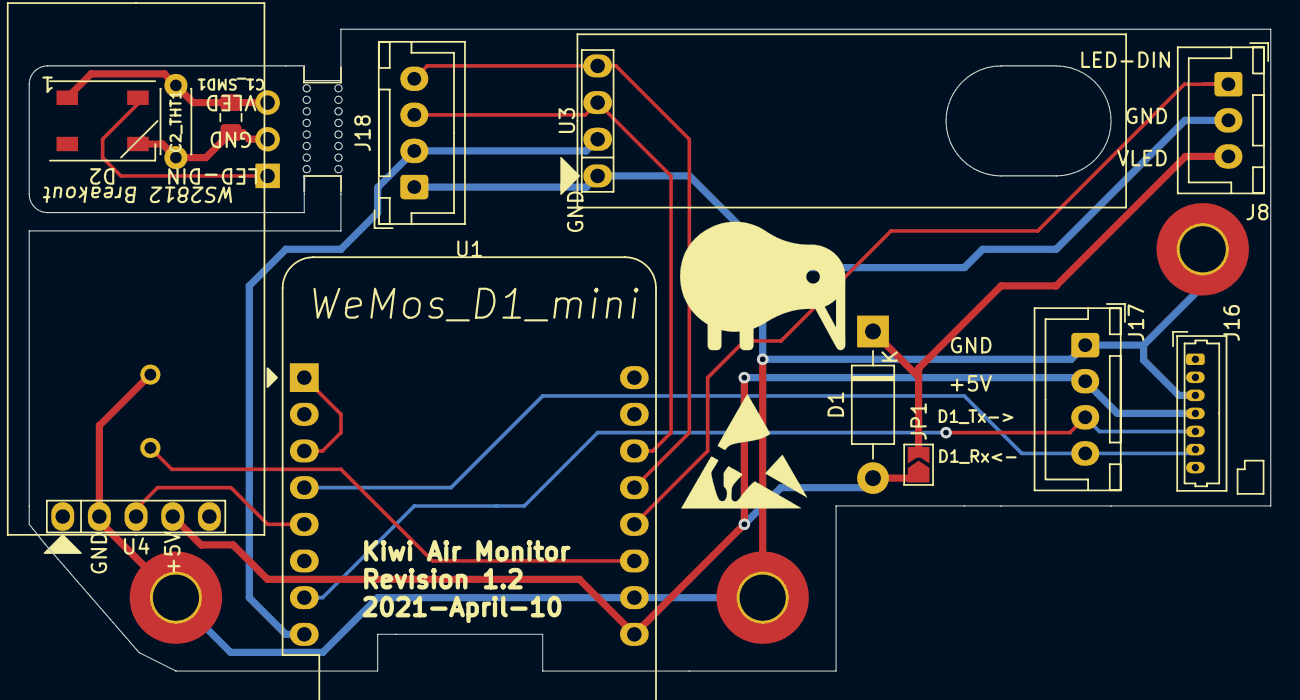
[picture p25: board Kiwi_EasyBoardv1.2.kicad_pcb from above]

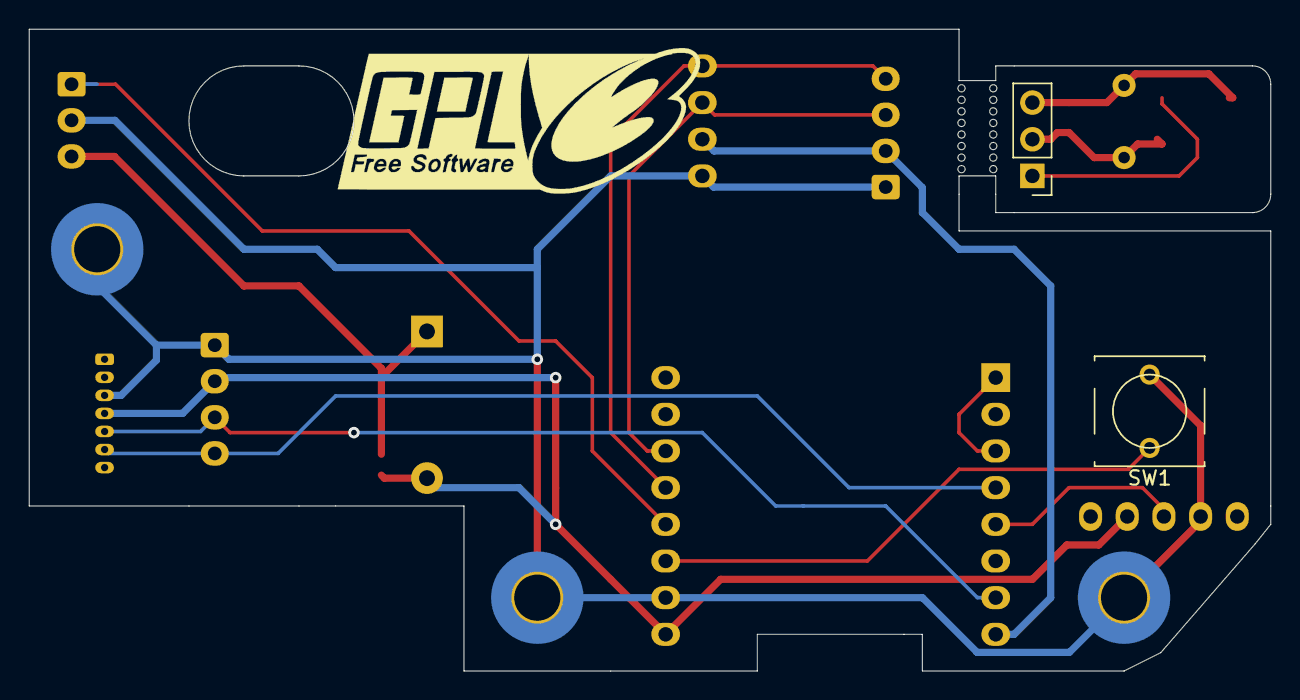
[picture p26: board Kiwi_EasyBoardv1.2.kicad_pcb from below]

Board: 2 copper layers, 86.0 x 44.5 mm, 21 parts (3 on the bottom side), 15 nets.

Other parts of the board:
mouse-bite-2.54mm-slot: VAL**; mouse-bite-2.54mm-slot

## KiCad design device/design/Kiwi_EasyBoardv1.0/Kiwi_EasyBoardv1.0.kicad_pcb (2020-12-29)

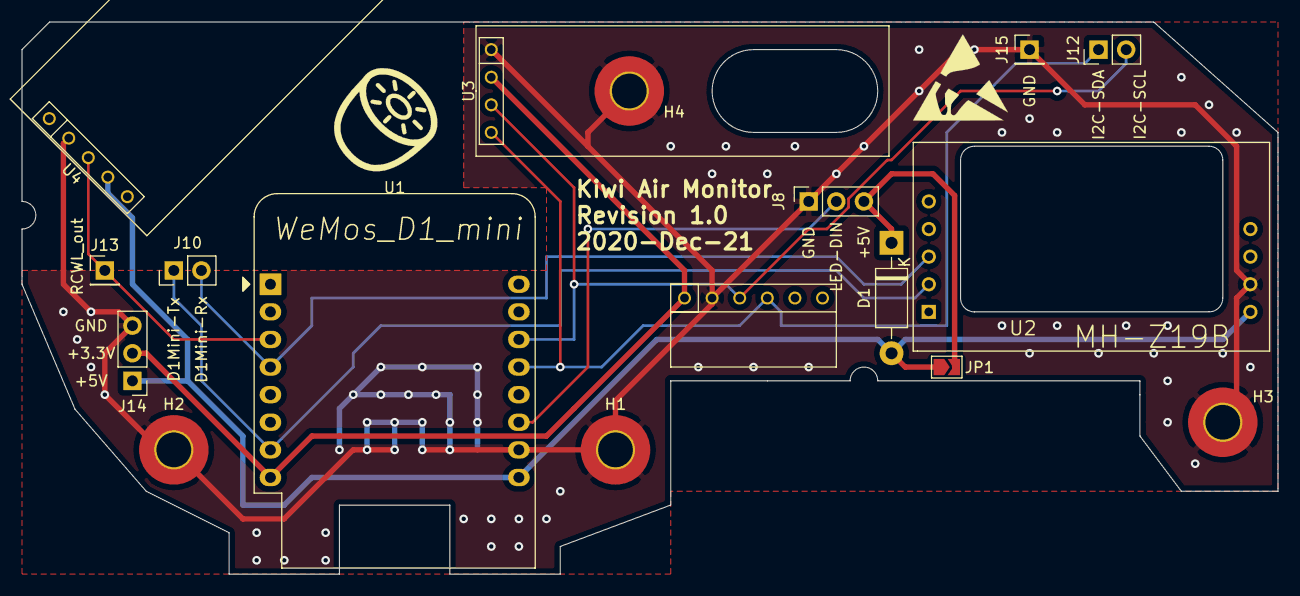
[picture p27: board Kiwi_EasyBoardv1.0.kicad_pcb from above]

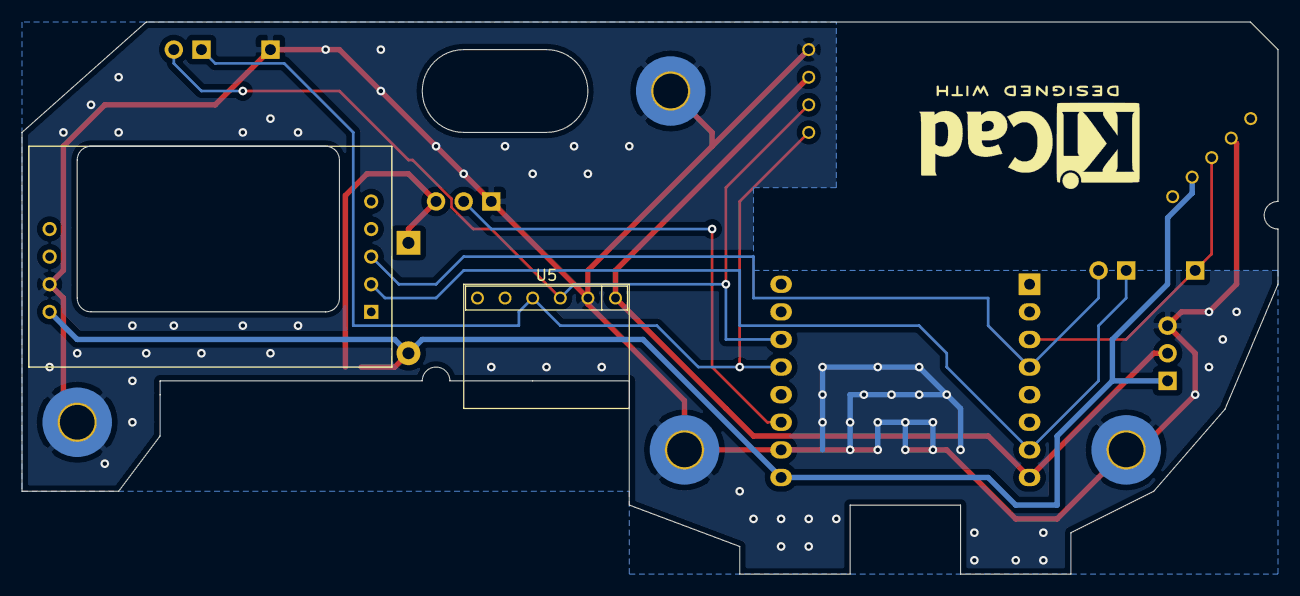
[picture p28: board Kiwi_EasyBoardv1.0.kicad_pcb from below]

Board: 2 copper layers, 115.6 x 50.8 mm, 18 parts (2 on the bottom side), 10 nets.

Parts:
D1: 1N4007; D_DO-41_SOD81_P10.16mm_Horizontal
GKiwi: LOGO; KiwiLogo
H1, H2, H3, H4: MountingHole_Pad; MountingHole_3.2mm_M3_Pad_TopBottom
J8: LED connector; PinSocket_1x03_P2.54mm_Vertical
J10: Conn_D1Mini_UART; PinHeader_1x02_P2.54mm_Vertical
J12: Conn_D1Mini_I2C; PinHeader_1x02_P2.54mm_Vertical
J13: Conn_RCWL_Out; PinHeader_1x01_P2.54mm_Vertical
J14: Conn_Power; PinHeader_1x03_P2.54mm_Vertical
J15: Conn_Ground; PinHeader_1x01_P2.54mm_Vertical
JP1: SolderJumper_2_Open; SolderJumper-2_P1.3mm_Open_TrianglePad1.0x1.5mm
U1: WeMos_D1_mini; WEMOS_D1_mini_light
U2: MH-Z19B; MH-Z19
U3: OLED_0.91_128x32
U4: RCWL-0516 Board; RCWL-0516
U5: BME280_Board

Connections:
+3V3: J14.2, U1.8, U3.2, U5.1
+5V: D1.2, J14.1, JP1.1, U1.9, U2.6, U4.4
/D1mini-UART-Rx: J10.2, U1.4, U2.3
/D1mini-UART-Tx: J10.1, U1.7, U2.2
/I2C-SCL: J12.2, U1.14, U3.3, U5.3
/I2C-SDA: J12.1, U1.13, U3.4, U5.4
/LED-DIN: J8.2, U1.11
/RCWL-OUT: J13.1, U1.3, U4.3
/VLED: D1.1, J8.3, JP1.2
GND: H1.1, H2.1, H3.1, H4.1, J8.1, J14.3, J15.1, U1.10, U2.7, U3.1, U4.2, U5.2

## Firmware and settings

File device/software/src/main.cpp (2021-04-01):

#include <Arduino.h>
#include <Wire.h>
#include "shared-timer.hpp"
#include "user-config.h"
#include "sensors/sensors.hpp"
#include "output/outputs.hpp"
#include "service/wifi-connection.hpp"
#include "service/ota-updates.hpp"
#include "service/mqtt-connection.hpp"
#include "service/status.hpp"

ADC_MODE(ADC_VCC);

KiwiTimer timer;
KiwiTimer highResTimer;

bool tickNormalTimer(void *) {
  highResTimer.in(timer.tick(), tickNormalTimer);
  return false;
}

WifiConnection *wifi;
Sensors *sensors;
Outputs *outputs;

MqttConnection *mqttCon;
OTAUpdates *ota;
Status *status;

/*
CO2: TX: D8, RX: D5
I2C: SCL/SCK: D1 & SDA: D2
Led: D4
Extra Temp: D7
Dust: tx: D3. rx: D6
*/

void setup() {
  Serial.begin(74880);
  // setup I2C on the correct pins
  Wire.begin(D2, D1);
  wifi = new WifiConnection(timer);
  mqttCon = new MqttConnection(wifi, timer);
  ota = new OTAUpdates(wifi, mqttCon, timer);
  sensors = new Sensors(timer);
  status = new Status(wifi, mqttCon, timer);
  outputs = new Outputs(sensors, mqttCon, status, timer, &highResTimer);
  highResTimer.in(10, tickNormalTimer);
}



void loop() { 
  delay(highResTimer.tick());
}

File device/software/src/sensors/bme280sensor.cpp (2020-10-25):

#include "sensors/bme280sensor.hpp"
#include <Wire.h>

BME280Sensor::BME280Sensor(){
    valid = bme.begin(0x76, &Wire);

    if (!valid) {
        Serial.println("Could not find a valid BME280 sensor, check wiring, address, sensor ID!");
        Serial.print("SensorID was: 0x");
        Serial.println(bme.sensorID(), 16);
        return;
    }
    Serial.println("Sensor found!");
    bme.setSampling(Adafruit_BME280::MODE_NORMAL,
                    Adafruit_BME280::SAMPLING_X8, // temperature
                    Adafruit_BME280::SAMPLING_X8, // pressure
                    Adafruit_BME280::SAMPLING_X8, // humidity
                    Adafruit_BME280::FILTER_OFF,
                    Adafruit_BME280::STANDBY_MS_1000);
}


void BME280Sensor::measure(float &temp, float &humidity, float &pressure) {
    if (!valid) {
        temp = NAN;
        humidity = NAN;
        pressure = NAN;
    }
    else {
        temp = bme.readTemperature();
        humidity = bme.readHumidity();
        pressure = bme.readPressure();
    }
}

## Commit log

2020-10-15 Started with initial prototypes
    [components.fzz]
2020-10-16 Imported MHZ19 sensor implementation from EspEasy
2020-10-16 Started writing new sensor framework with smoothing
2020-10-16 Switched BME sensors to sensor package
2020-10-16 For now turn off sensor reset
2020-10-17 Better operation of the bme280 sensor
2020-10-17 Switching back to normal mh-z19 library
2020-10-19 Wrote first version of hardware list
    [components.fzz]
2020-10-20 Added costs remark about the sensor
2020-10-25 Added support for rcwl sensor in code
2020-10-25 Switching more and more to timers
2020-10-25 Added RCWL sensor to build list
2020-10-26 Improved how the movement detection sensor works
2020-10-26 Switching back to the ESP easy based sensor fixes #22
2020-10-26 Updated wiring diagram to fit the PIR sensor
    resolves #6
    [components.fzz]
2020-10-26 Added a way to mark failing sensors, to avoid it keep repeating the old value
    Resolves #21
2020-10-27 Temporarily importing arduino timer code, untill the new version is published at pio
2020-10-28 Fixed includes for timer
2020-10-29 Updated arduino-timer clone
2020-10-31 Updated arduino-timer to 2.1.1 release untill on pio
2020-11-01 Switched display to timer code
2020-11-01 Improved timer code with the define
2020-11-03 correct influx insert
2020-11-06 Switch display to always show all values and plot latest half hour, except if no movement detected
2020-11-06 Also publish voltage to the server, so we can track power loss
2020-11-10 Update docs NL en hoofd readme gebaseerd op info die al aanwezig was.
2020-11-11 Display and led improvements
2020-11-16 Switch to multistage build and multiarch
2020-11-17 Rewrote some stuff about design and switch the main chip
2020-11-21 Added calibrate code for 4 co2 sensors in one round
2020-11-23 Fixes to the calibration tool
    [main.cpp]
2020-11-30 Fixed choppy eye timer
    [main.cpp]
2020-11-30 Wrote how to make the cable for the co2 sensor
2021-01-16 Latest changes to the co2 calibration code
2021-01-16 Implemented co2 sensor code based on wifwafs library
2021-01-24 Created directory structure for EasyBoardv1.0 and v1.1
    [BME280_SENSOR_MODULE.STEP, BME280_SENSOR_MODULE_WITH_HEADER.STEP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]
2021-01-26 Removing remainders of calibration
2021-01-26 Also updated manuals to remove calibration section
2021-01-26 Removed final comment related to old sensor library
2021-01-27 Moved LED to D3 to avoid blue flickering light in the wemos
2021-01-29 Update the Hardware manual, added the step files, and the solderhelper
    [Kiwi1.1.SolderHelper.stl, Kiwi_EasyBoardv1.1.NoComponents.step, components.fzz]
2021-04-01 Improved display rendering
    - If no presence sensor detected and CO2 has been below 550 for a long time, don't render
    - Print mac address and connection status at startup for easy debugging (fix #38)
    [main.cpp]
2021-04-21 Hardware design files of the board version 1.2
    [BME280_SENSOR_MODULE.STEP, BME280_SENSOR_MODULE_WITH_HEADER.STEP, Kiwi_EasyBoardv1.2.kicad_pcb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]
2021-05-11 Updated new port for the RCWL sensor on the new PCB
2021-12-13 Tuning of led for more yellow look on warning
2022-01-29 Allowed configuration of RCWL sensor sensitivity
2022-01-29 Render display more often to improve snappyness of the movement sensor based sleep
2022-01-31 Avoid recalculating the checksum of the image every 10 seconds
    [ota-updates.cpp]
